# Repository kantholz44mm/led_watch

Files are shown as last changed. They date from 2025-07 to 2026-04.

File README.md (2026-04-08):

# Description

It's a wristwatch using LEDs to show the current time. This repository contains one major folder for the hardware part, which contains a KiCAD project with the schematics & PCB layout, as well as a FreeCAD project with 3D-printable parts for the case. You can find instructions on how to use each "part" of the repo in the subfolders.

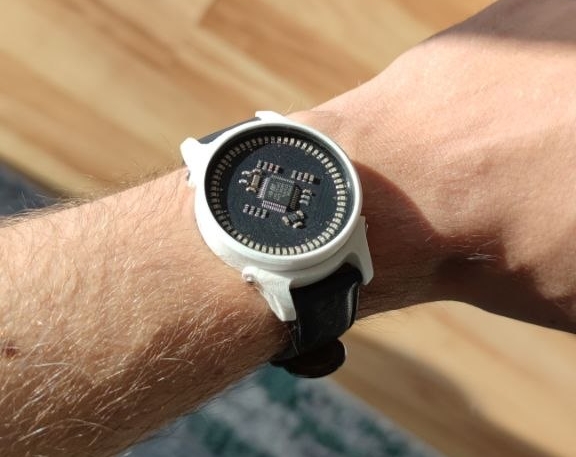
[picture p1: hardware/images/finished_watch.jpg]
Image of finished Wristwatch


# How it works

The watch has a (very) low power STM32 microcontroller, as well as a Bosch BMA400 accelerometer for user inputs. It also has a 32 kHz crystal for precise timekeeping. A ring of 60 LEDs shows the hour and minute hands when the watch is doubletapped on its X axis. When not displaying the time, all components are put into their lowest possible power modes, consuming ~9uA total. Since the device is powered by a single CR2032 or CR2016 coin cell on the back of the PCB, this results in a theoretical maximum runtime of up to ~2.9. I have not had time to test this fully, but my personal watch has been going strong on a single cell for around 7 months with daily use. Battery lifetime of course heavily depends on how often the display is activated.

# Design Goals

- Long battery life & Easy battery replacement
- Small diameter (currently 38mm without the case)
- Manufacturability (case is 3D-printable or machineable)
- Water-tightness

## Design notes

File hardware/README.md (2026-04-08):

# Schematics

The whole watch is built around an STM32L071 low power MCU. There's also a Bosch BMA400 accelerometer used for detecting taps and the absolute orientation for setting the time, bubble-level syle. The MCU has a 32KHz for precise timekeeping. The LED ring is segmented into 4 groups of 15 to drastically reduce routing complexity and part count. As a consequence, only 1 LED per group can be active at a time. In the current software, only 1 LED in total is ever on at a time. The accelerometer communicates with the MCU via I2C for configuration and has a shared interrupt line for wakeup. You can find the full schematics under `hardware/export/watch.pdf`.

# Case

There's two case designs, which are very similar: There's a Unibody with only one outer shell, as well as a bottom lid for easy battery replacement, and one body with two separate handle pieces, which makes the body part rotationally symmetric for those who might want to machine the parts on a lathe. For both cases, you'll need 4 1.6x8mm screws to hold everything together, as well as a 38mm watch-glass/crystal. You'll also need two gaskets, both of which can either be purchased, or, as I did, 3D printed from TPU. There's the FreeCAD project file, as well as STEP files for all parts. The STEP files can be found under `hardware/export/`.

# PCB

The PCB was created using KiCAD. The project includes part numbers for ordering with automated assembly from JLCPCB. You can find the exported gerber files (ready to order) in the folder `hardware/export`.

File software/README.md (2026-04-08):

# Description

The firmware of the watch currently implements showing the time and temperature, as well as setting the time. Every LED display feature has some neat animations where the lit up LED "runs" to the new target over some period of time.

Everything is built ontop of a custom HAL layer which uses only CMSIS headers as a dependency. As such, the firmware is fully self-contained as it is within the repo, with no other external dependencies.

# Prerequisites

- ARM compiler toolchain (`arm-none-eabi-xxx`)
- GNU Make
- Debugger/Programmer
- Needle adapter or soldering iron & wires

You will need an ARM compiler to build the firmware. The build process is done using a single Makefile. To flash the code to the device, you'll also need a programmer or debugger. I personally use a JLink one within VS Code, so there's a configuration for that in the project. The hardware currently only has testpoints for attaching a debugger via SWD, but they're quite big and can easily be soldered to.

# Getting started

To compile, just go into the `software` folder and do

`make`

This should output a finished binary at `software/bin/main.elf`.

# Using the firmware

The firmware implements the following state machine for its UX:

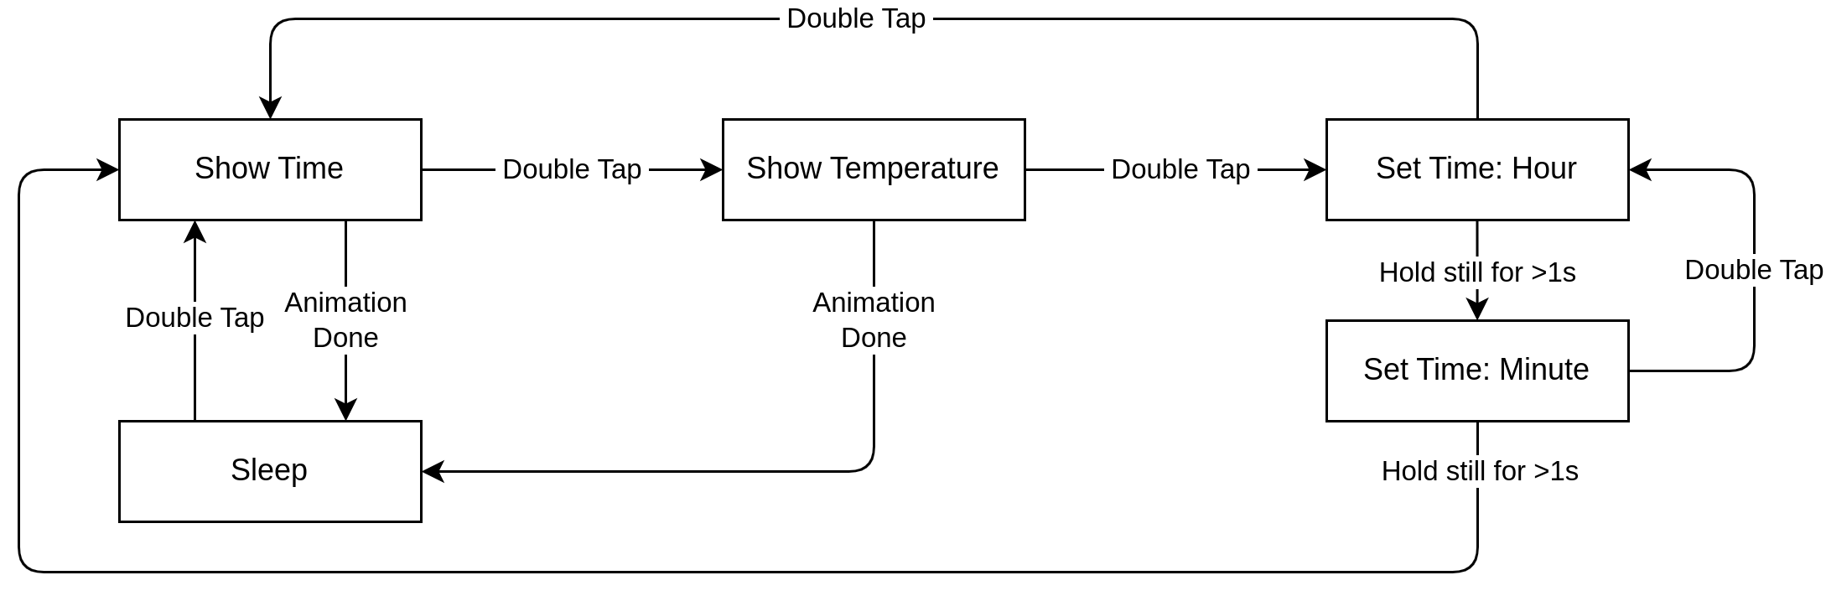
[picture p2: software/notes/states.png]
Image of the state machine of inputs


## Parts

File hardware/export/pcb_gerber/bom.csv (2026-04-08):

Designator | Footprint | Quantity | Value | LCSC Part #
C1, C10, C11, C2, C3, C4, C5, C9 | 0603 | 8 | 100nF | C91183
C12, C13 | 0603 | 2 | 22uF | C86295
C7, C8 | 0603 | 2 | 19pF | C527046
D1, D10, D11, D12, D13, D14, D15, D16, D17, D18, D19, D2, D20, D21, D22, D23, D24, D25, D26, D27, D28, D29, D3, D30, D31, D32, D33, D34, D35, D36, D37, D38, D39, D4, D40, D41, D42, D43, D44, D45, D46, D47, D48, D49, D5, D50, D51, D52, D53, D54, D55, D56, D57, D58, D59, D6, D60, D7, D8, D9 | 0603 | 60 | LED | C284922
R1, R2 | 0603 | 2 | 4.7k | C23162
R10, R8, R9 | 0603 | 3 | 22 | C23345
R3 | 0603 | 1 | 100K | C25805
R4, R5, R6, R7 | 0603 | 4 | 160 | C22814
U1 | LQFP-48_7x7mm_P0.5mm | 1 | STM32L071CBTx | C79758
U2 | LGA-12_2x2mm_P0.5mm | 1 | BOSCH BMA400 | C437655
Y1 | Crystal_SMD_3215-2Pin_3.2x1.5mm | 1 | 3131M-32.768DTTLRRL | C42438016

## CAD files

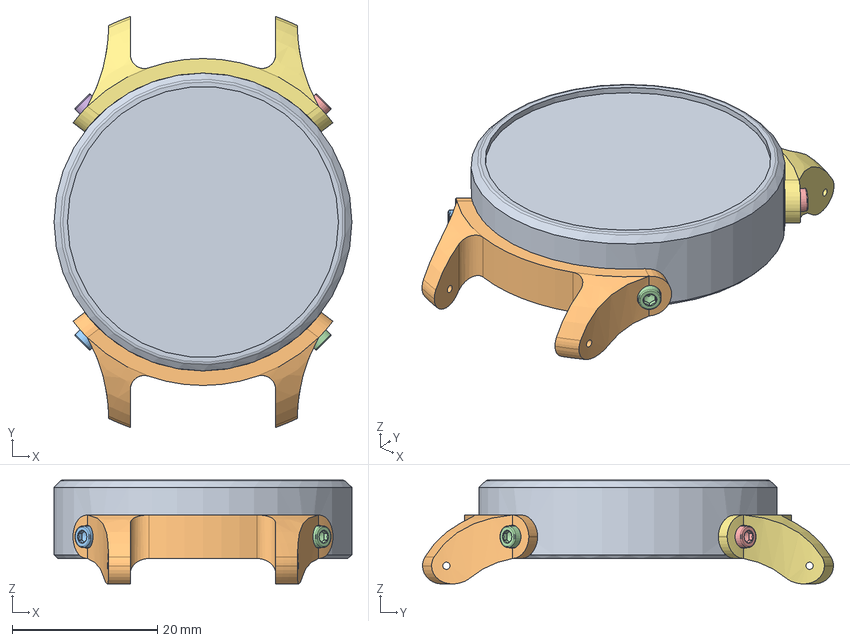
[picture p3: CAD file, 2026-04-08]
hardware/case.FCStd
41.0 x 56.6 x 14.3 mm
Glass
C_0603_1608Metric
LED_0603_1608Metric
LED_0603_1608Metric001
LED_0603_1608Metric002
R_0603_1608Metric
LED_0603_1608Metric003
R_0603_1608Metric001
LED_0603_1608Metric004
LED_0603_1608Metric005
LED_0603_1608Metric006
LED_0603_1608Metric007
LED_0603_1608Metric008
R_0603_1608Metric002
LED_0603_1608Metric009
LED_0603_1608Metric010
C_0603_1608Metric001
LED_0603_1608Metric011
LED_0603_1608Metric012
LED_0603_1608Metric013
C_0603_1608Metric002
LED_0603_1608Metric014
LED_0603_1608Metric015
LED_0603_1608Metric016
LED_0603_1608Metric017
R_0603_1608Metric003
LQFP-48_7x7mm_P0.5mm
R_0603_1608Metric004
R_0603_1608Metric005
LED_0603_1608Metric018
Crystal_SMD_3215-2Pin_3.2x1.5mm
C_0603_1608Metric003
R_0603_1608Metric006
C_0603_1608Metric004
LED_0603_1608Metric019
LED_0603_1608Metric020
LED_0603_1608Metric021
LED_0603_1608Metric022
LED_0603_1608Metric023
LED_0603_1608Metric024
LED_0603_1608Metric025
LED_0603_1608Metric026
LED_0603_1608Metric027
R_0603_1608Metric007
LED_0603_1608Metric028
LED_0603_1608Metric029
LED_0603_1608Metric030
LED_0603_1608Metric031
R_0603_1608Metric008
LED_0603_1608Metric032
LED_0603_1608Metric033
LED_0603_1608Metric034
LED_0603_1608Metric035
LED_0603_1608Metric036
C_0603_1608Metric005
LED_0603_1608Metric037
LED_0603_1608Metric038
LED_0603_1608Metric039
C_0603_1608Metric006
LED_0603_1608Metric040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

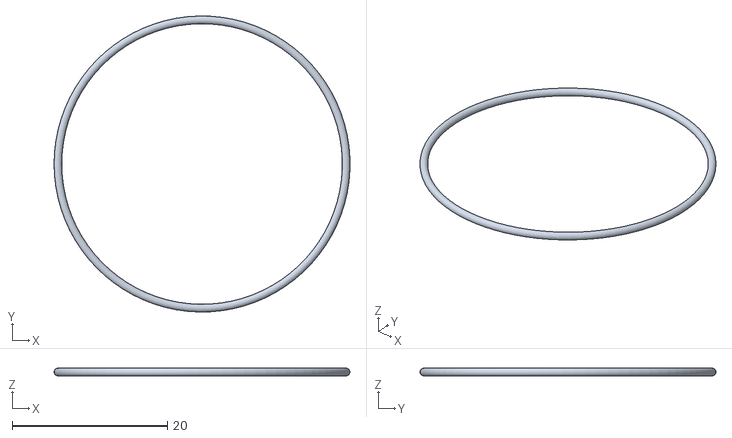
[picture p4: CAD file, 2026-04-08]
hardware/export/LowerGasket.stl
38.1 x 38.1 x 0.993

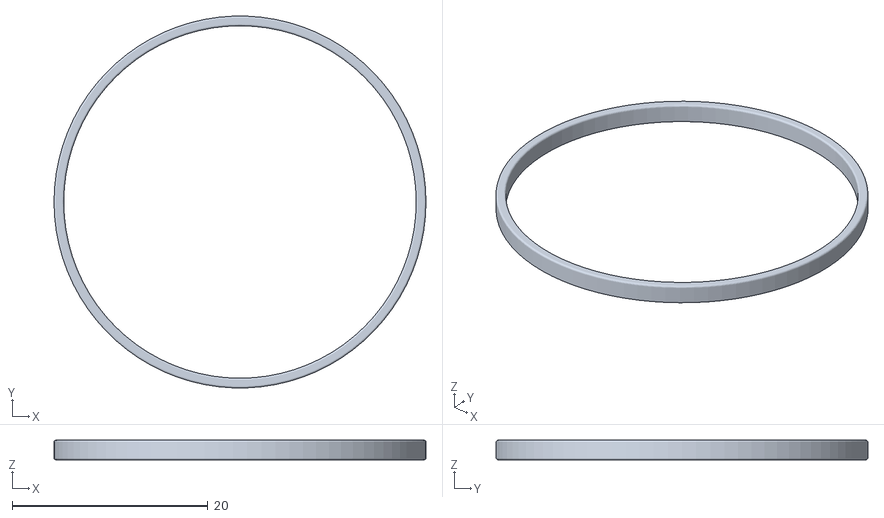
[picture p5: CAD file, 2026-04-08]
hardware/export/UpperGasket.stl
38.0 x 38.0 x 2.00

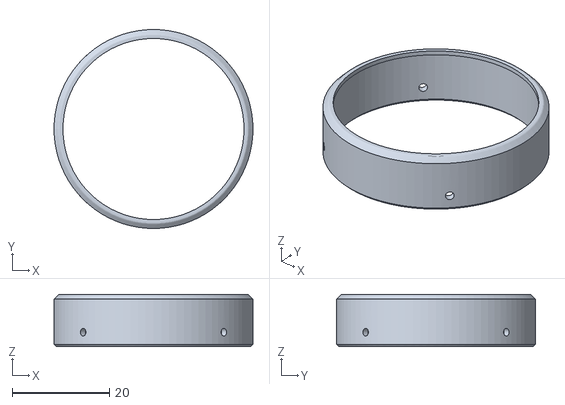
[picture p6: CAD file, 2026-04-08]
hardware/export/Body.stl
41.0 x 41.0 x 10.8

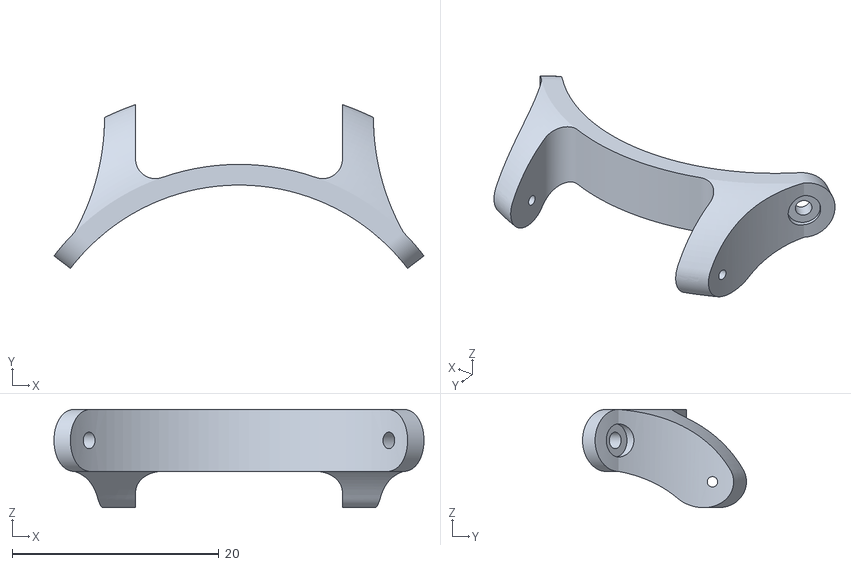
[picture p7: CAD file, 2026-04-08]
hardware/export/Handle.stl
35.8 x 15.8 x 9.50

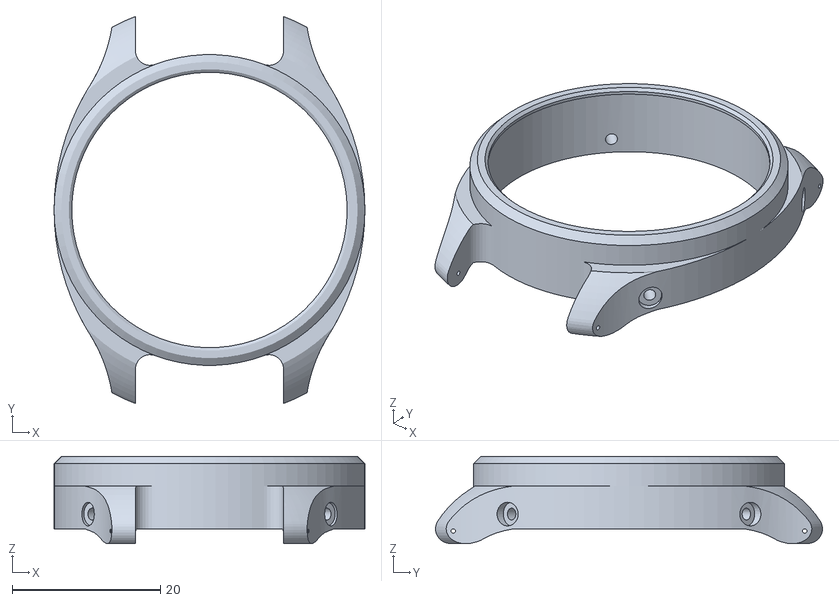
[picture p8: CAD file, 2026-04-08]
hardware/export/Unibody.stl
42.0 x 52.3 x 11.8

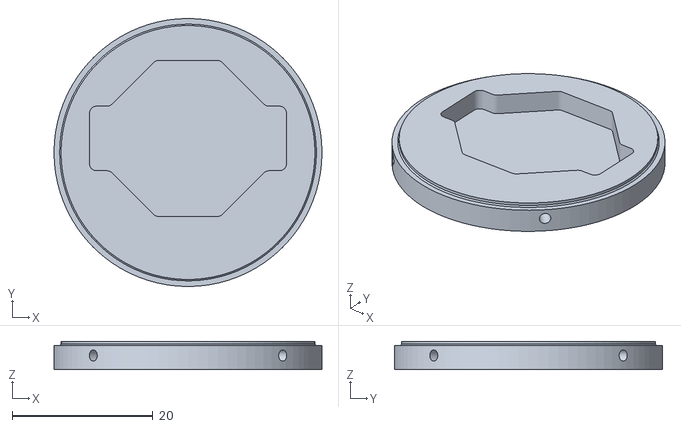
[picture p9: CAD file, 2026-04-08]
hardware/export/Bottom.stl
38.1 x 38.1 x 4.00

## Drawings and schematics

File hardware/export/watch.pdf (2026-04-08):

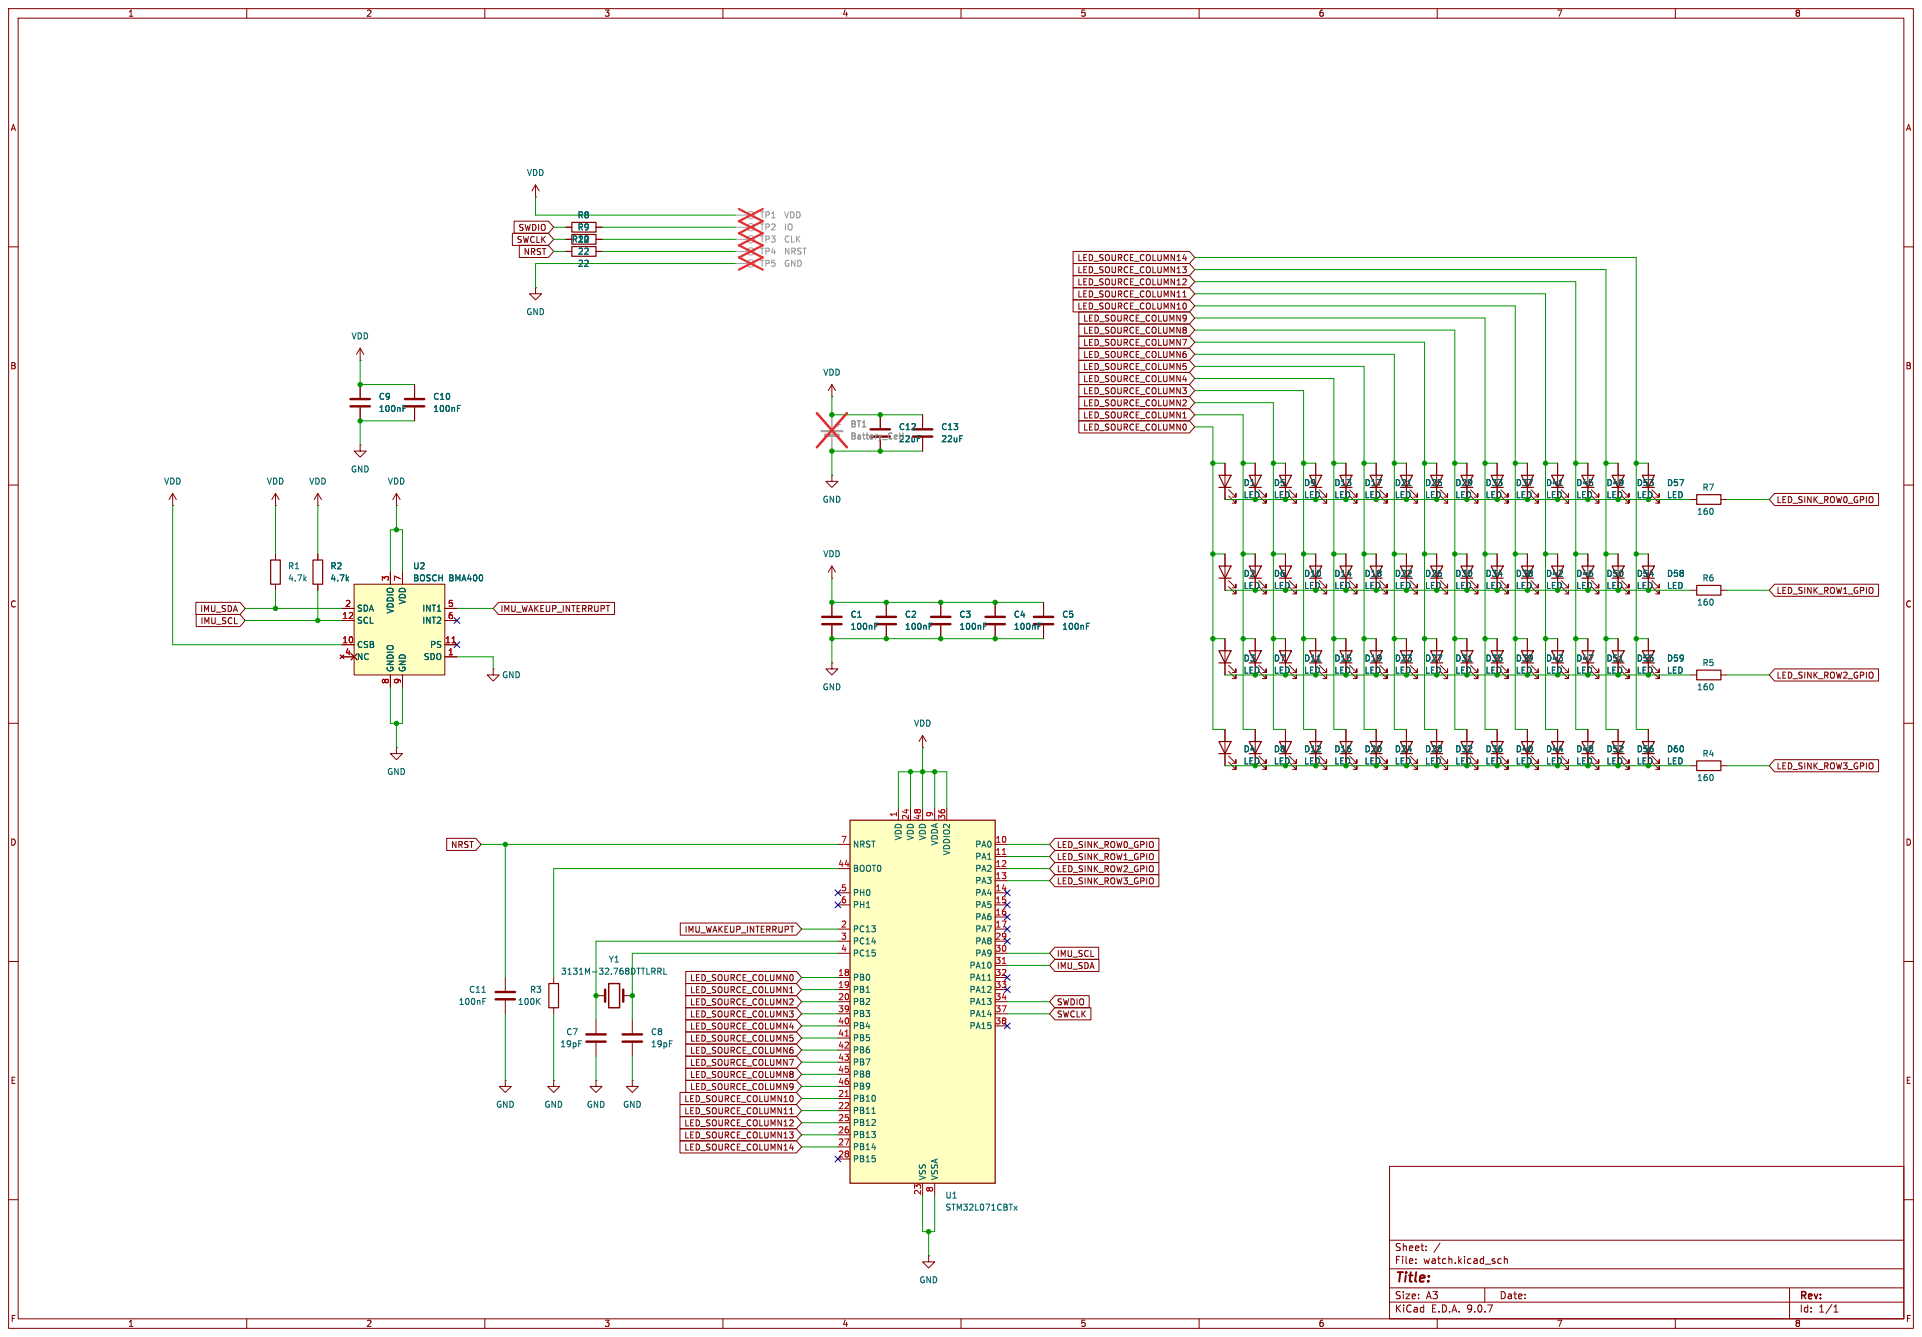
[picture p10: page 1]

1 VDD 24 VDD 48 VSS 23 VDDA

Id: 1/1 Title: File: watch.kicad_sch Sheet: / R3

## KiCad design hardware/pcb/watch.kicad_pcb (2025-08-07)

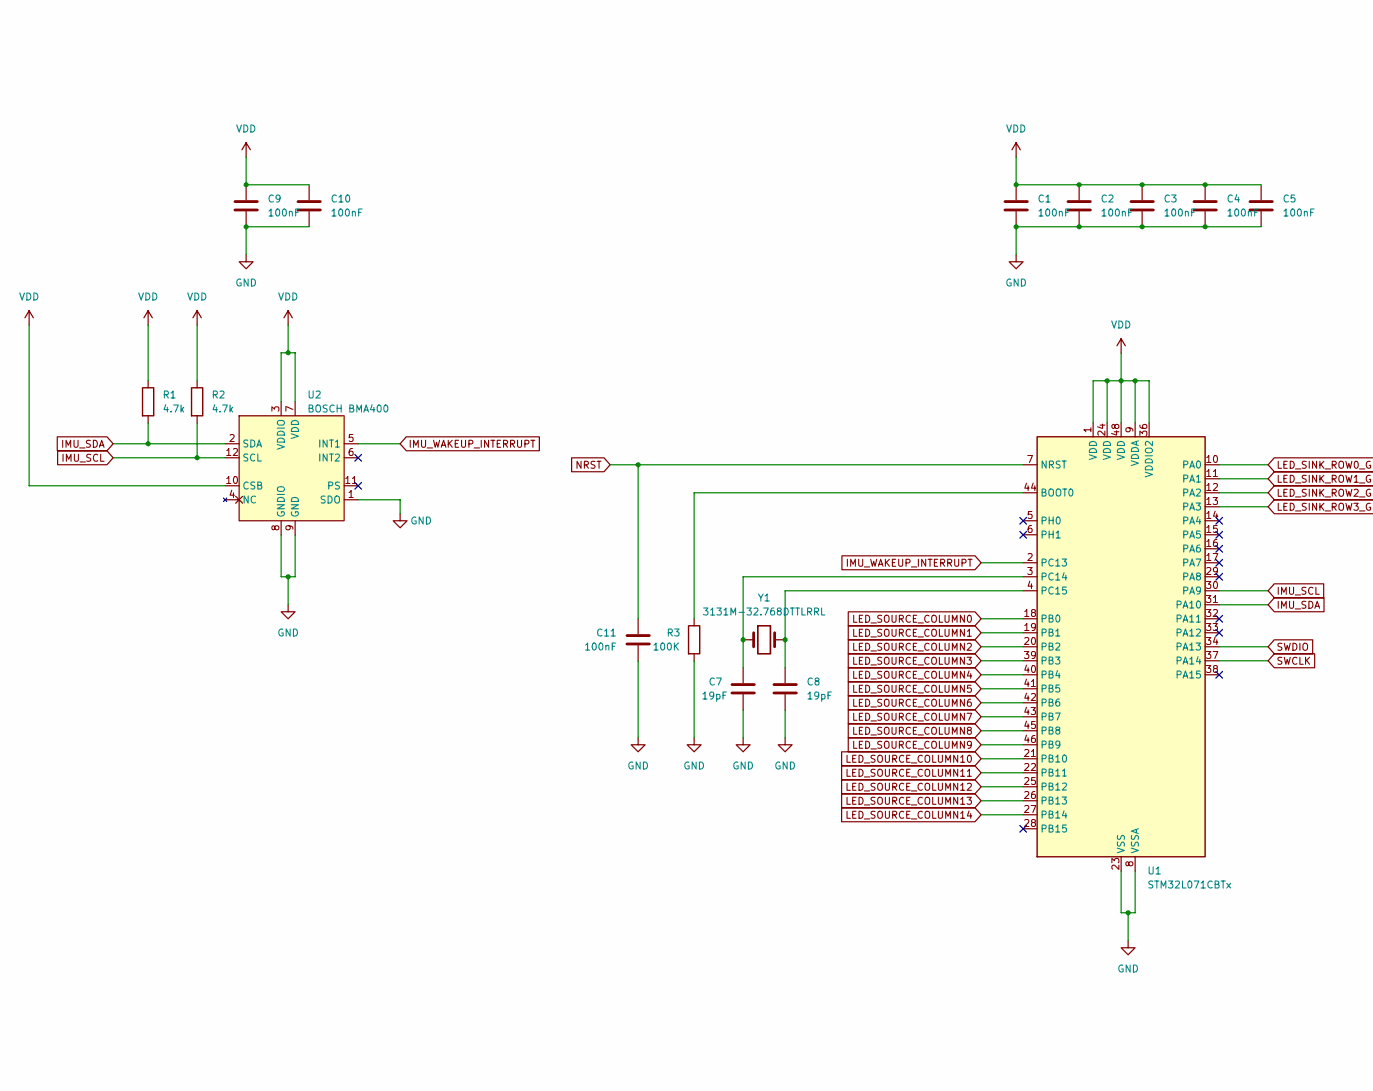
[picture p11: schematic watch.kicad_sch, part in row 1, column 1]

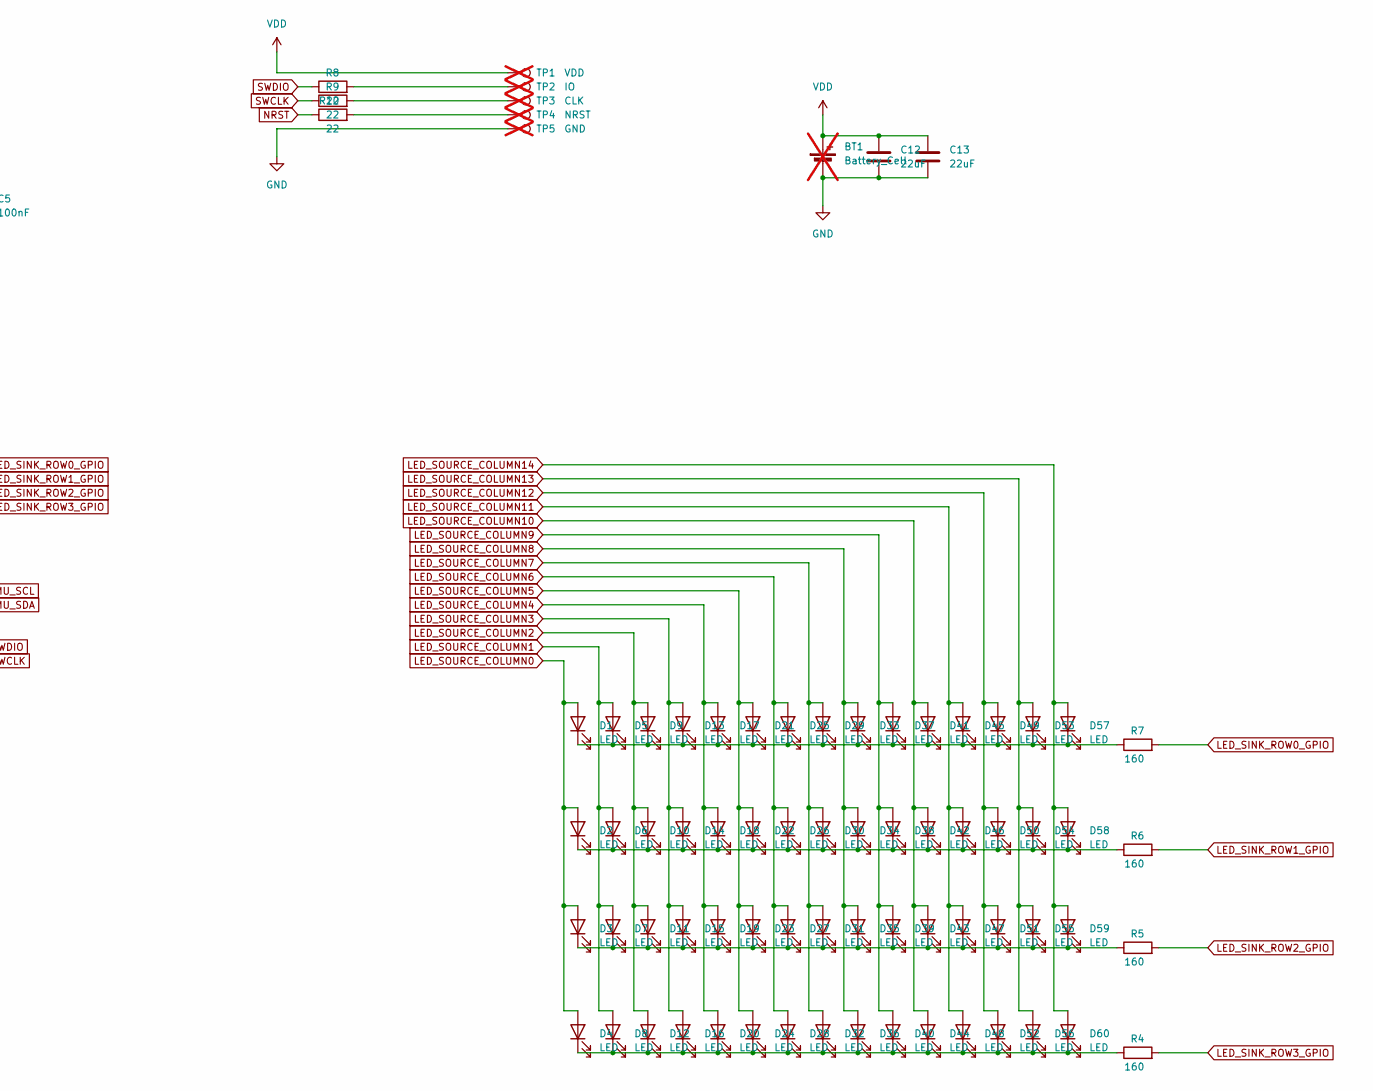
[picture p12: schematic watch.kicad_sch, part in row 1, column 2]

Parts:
BT1: Battery_Cell; BatteryHolder_MPD_BC2003_1x2032; not fitted
C1, C2, C3, C4, C5, C9, C10, C11: 100nF; C_0603_1608Metric; LCSC Part # C91183
C7, C8: 19pF; C_0603_1608Metric; LCSC Part # C527046
C12, C13: 22uF; C_0603_1608Metric; LCSC Part # C86295
D1, D2, D3, D4, D5, D6, D7, D8, D9, D10, D11, D12, D13, D14, D15, D16, D17, D18, D19, D20, D21, D22, D23, D24, D25, D26, D27, D28, D29, D30, D31, D32, D33, D34, D35, D36, D37, D38, D39, D40, D41, D42, D43, D44, D45, D46, D47, D48, D49, D50, D51, D52, D53, D54, D55, D56, D57, D58, D59, D60: LED; 0603; LCSC Part # C284922
R1, R2: 4.7k; R_0603_1608Metric; LCSC Part # C23162
R3: 100K; R_0603_1608Metric; LCSC Part # C25805
R4, R5, R6, R7: 160; R_0603_1608Metric; LCSC Part # C22814
R8, R9, R10: 22; R_0603_1608Metric; LCSC Part # C23345
TP1: VDD; TestPoint_Pad_D2.0mm; not fitted
TP2: IO; TestPoint_Pad_D2.0mm; not fitted
TP3: CLK; TestPoint_Pad_D2.0mm; not fitted
TP4: NRST; TestPoint_Pad_D2.0mm; not fitted
TP5: GND; TestPoint_Pad_D2.0mm; not fitted
U1: STM32L071CBTx; LQFP-48_7x7mm_P0.5mm; LCSC Part # C79758
U2: BOSCH BMA400; LGA-12_2x2mm_P0.5mm; LCSC Part # C437655
Y1: 3131M-32.768DTTLRRL; Crystal_SMD_3215-2Pin_3.2x1.5mm; LCSC Part # C42438016

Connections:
GND: BT1.2 (-), C1.1, C2.1, C3.1, C4.1, C5.1, C7.2, C8.2, C9.1, C10.1, C11.1, C12.1, C13.1, R3.2, TP5.1, U1.8 (VSSA), U1.23 (VSS), U1.35 (VSS), U1.47 (VSS), U2.1 (SDO), U2.8 (GNDIO), U2.9 (GND)
IMU_SCL: R2.2, U1.30 (PA9), U2.12 (SCL)
IMU_SDA: R1.2, U1.31 (PA10), U2.2 (SDA)
IMU_WAKEUP_INTERRUPT: U1.2 (PC13), U2.5 (INT1)
LED_SINK_ROW0_GPIO: R7.2, U1.10 (PA0)
LED_SINK_ROW1_GPIO: R6.2, U1.11 (PA1)
LED_SINK_ROW2_GPIO: R5.2, U1.12 (PA2)
LED_SINK_ROW3_GPIO: R4.2, U1.13 (PA3)
LED_SOURCE_COLUMN0: D1.2 (A), D2.2 (A), D3.2 (A), D4.2 (A), U1.18 (PB0)
LED_SOURCE_COLUMN1: D5.2 (A), D6.2 (A), D7.2 (A), D8.2 (A), U1.19 (PB1)
LED_SOURCE_COLUMN2: D9.2 (A), D10.2 (A), D11.2 (A), D12.2 (A), U1.20 (PB2)
LED_SOURCE_COLUMN3: D13.2 (A), D14.2 (A), D15.2 (A), D16.2 (A), U1.39 (PB3)
LED_SOURCE_COLUMN4: D17.2 (A), D18.2 (A), D19.2 (A), D20.2 (A), U1.40 (PB4)
LED_SOURCE_COLUMN5: D21.2 (A), D22.2 (A), D23.2 (A), D24.2 (A), U1.41 (PB5)
LED_SOURCE_COLUMN6: D25.2 (A), D26.2 (A), D27.2 (A), D28.2 (A), U1.42 (PB6)
LED_SOURCE_COLUMN7: D29.2 (A), D30.2 (A), D31.2 (A), D32.2 (A), U1.43 (PB7)
LED_SOURCE_COLUMN8: D33.2 (A), D34.2 (A), D35.2 (A), D36.2 (A), U1.45 (PB8)
LED_SOURCE_COLUMN9: D37.2 (A), D38.2 (A), D39.2 (A), D40.2 (A), U1.46 (PB9)
LED_SOURCE_COLUMN10: D41.2 (A), D42.2 (A), D43.2 (A), D44.2 (A), U1.21 (PB10)
LED_SOURCE_COLUMN11: D45.2 (A), D46.2 (A), D47.2 (A), D48.2 (A), U1.22 (PB11)
LED_SOURCE_COLUMN12: D49.2 (A), D50.2 (A), D51.2 (A), D52.2 (A), U1.25 (PB12)
LED_SOURCE_COLUMN13: D53.2 (A), D54.2 (A), D55.2 (A), D56.2 (A), U1.26 (PB13)
LED_SOURCE_COLUMN14: D57.2 (A), D58.2 (A), D59.2 (A), D60.2 (A), U1.27 (PB14)
NRST: C11.2, R10.1, U1.7 (NRST)
unnamed: D1.1 (K), D5.1 (K), D9.1 (K), D13.1 (K), D17.1 (K), D21.1 (K), D25.1 (K), D29.1 (K), D33.1 (K), D37.1 (K), D41.1 (K), D45.1 (K), D49.1 (K), D53.1 (K), D57.1 (K), R7.1
unnamed: D2.1 (K), D6.1 (K), D10.1 (K), D14.1 (K), D18.1 (K), D22.1 (K), D26.1 (K), D30.1 (K), D34.1 (K), D38.1 (K), D42.1 (K), D46.1 (K), D50.1 (K), D54.1 (K), D58.1 (K), R6.1
unnamed: D3.1 (K), D7.1 (K), D11.1 (K), D15.1 (K), D19.1 (K), D23.1 (K), D27.1 (K), D31.1 (K), D35.1 (K), D39.1 (K), D43.1 (K), D47.1 (K), D51.1 (K), D55.1 (K), D59.1 (K), R5.1
unnamed: D4.1 (K), D8.1 (K), D12.1 (K), D16.1 (K), D20.1 (K), D24.1 (K), D28.1 (K), D32.1 (K), D36.1 (K), D40.1 (K), D44.1 (K), D48.1 (K), D52.1 (K), D56.1 (K), D60.1 (K), R4.1
unnamed: R8.2, TP2.1
unnamed: R9.2, TP3.1
unnamed: R10.2, TP4.1
unnamed: R3.1, U1.44 (BOOT0)
unnamed: C7.1, U1.3 (PC14), Y1.1
unnamed: C8.1, U1.4 (PC15), Y1.2
SWCLK: R9.1, U1.37 (PA14)
SWDIO: R8.1, U1.34 (PA13)
VDD: BT1.1 (+), C1.2, C2.2, C3.2, C4.2, C5.2, C9.2, C10.2, C12.2, C13.2, R1.1, R2.1, TP1.1, U1.1 (VDD), U1.9 (VDDA), U1.24 (VDD), U1.36 (VDDIO2), U1.48 (VDD), U2.3 (VDDIO), U2.7 (VDD), U2.10 (CSB)

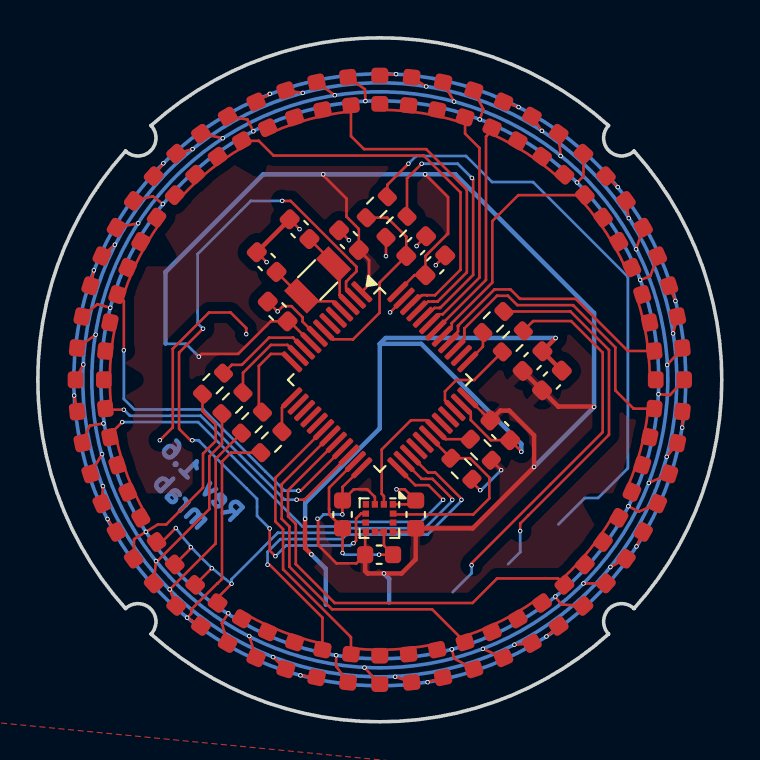
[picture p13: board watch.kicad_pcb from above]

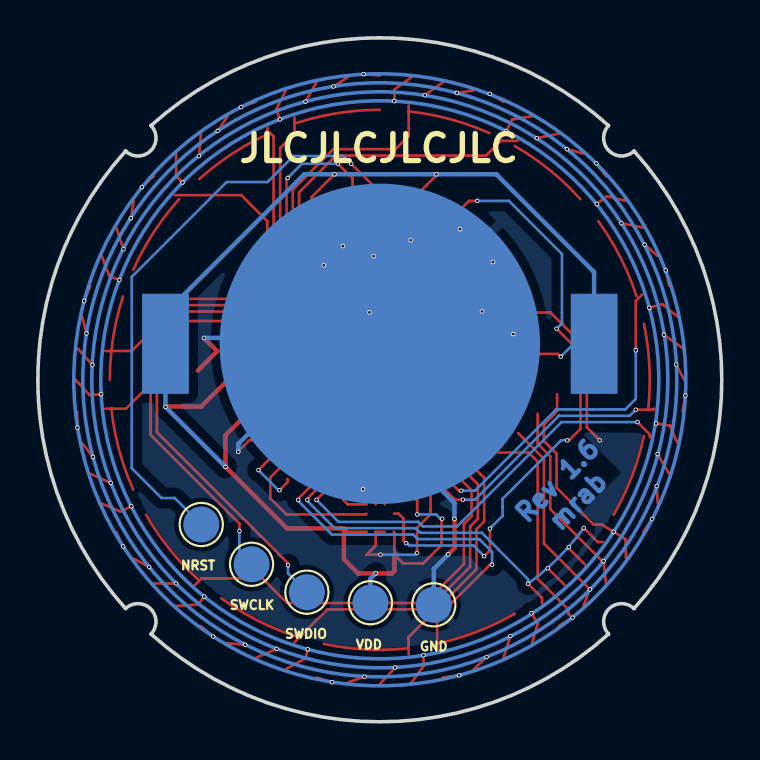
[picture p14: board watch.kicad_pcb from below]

Board: 2 copper layers, 38.0 x 38.0 mm, 91 parts (6 on the bottom side), 37 nets.

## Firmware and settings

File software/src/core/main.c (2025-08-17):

#include "hal/led.h"
#include "hal/i2c.h"
#include "hal/time.h"
#include "hal/gpio.h"
#include "hal/bma400.h"
#include "hal/rtc.h"
#include "animation.h"
#include "app/app.h"

int main(void)
{
    // initialize every peripheral needed
    time_init();
    rtc_init();
    led_init();
    i2c_init();
    bma400_init();
    animation_init();

    // the workhorse
    app_run();

    return 0;
}

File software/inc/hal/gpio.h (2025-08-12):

#pragma once
#include "types.h"
#include "cmsis/stm32l071xx.h"

#define GPIO_LOW   0
#define GPIO_HIGH  1

typedef enum {

    GPIO_PORT_A = 0,
    GPIO_PORT_B = 1,
    GPIO_PORT_C = 2,
    GPIO_PORT_D = 3,
    GPIO_PORT_E = 4,
    GPIO_PORT_H = 7

} gpio_port_t;

typedef enum {

    GPIO_MODE_INPUT     = 0b00,
    GPIO_MODE_OUTPUT    = 0b01,
    GPIO_MODE_ALTERNATE = 0b10,
    GPIO_MODE_ANALOG    = 0b11

} gpio_mode_t;


typedef enum {

    GPIO_OUTPUT_MODE_PUSHPULL  = 0b0,
    GPIO_OUTPUT_MODE_OPENDRAIN = 0b1

} gpio_output_mode_t;


typedef enum {

    GPIO_OUTPUT_SPEED_LOW       = 0b00,
    GPIO_OUTPUT_SPEED_MEDIUM    = 0b01,
    GPIO_OUTPUT_SPEED_HIGH      = 0b10,
    GPIO_OUTPUT_SPEED_VERY_HIGH = 0b11,

} gpio_output_speed_t;


typedef enum {

    GPIO_PULLUP_NONE = 0b00,
    GPIO_PULLUP_UP   = 0b01,
    GPIO_PULLUP_DOWN = 0b10,

} gpio_pulltype_t;



typedef struct {

    gpio_mode_t         mode;
    gpio_output_mode_t  output_mode;
    gpio_output_speed_t output_speed;
    gpio_pulltype_t     pulltype;
    u8                  alternate_mode;

} gpio_config_t;

void gpio_config(gpio_port_t port, u8 pin, gpio_config_t config);
u8 gpio_read(gpio_port_t port, u8 pin);
void gpio_write(gpio_port_t port, u8 pin, u8 value);

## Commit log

2021-11-21 Initial Draft
    [LED_Driver.sch, PowerSupply.sch, watch.kicad_pcb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]
2021-11-21 no more vias below metallic components; cleaned up some tracks
    [watch.kicad_pcb, watch.sch]
2021-11-22 V2 after Feedback
    [LED_Driver.sch, watch.kicad_pcb, watch.sch]
2021-11-24 testing gogs
    [LED_Driver.sch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]
2022-03-23 60 LED version
    [LED_Driver.kicad_sch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]
2022-04-07 as ordered
    [watch-B_Cu.gbl, watch-B_Cu.gbr, watch-B_Mask.gbr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]
2022-05-26 as ordered V1.4
    [LED_Driver.kicad_sch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]
2024-06-23 V2 initial schematic
    [LED_Driver.kicad_sch, LED_Driver.sch, LED_Matrix.kicad_sch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]
2024-06-24 V2 PCB first draft
    [LED_Matrix.kicad_sch, accel.kicad_sch, power.kicad_sch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]
2024-06-24 cleaned up silkscreen
    [watch.kicad_pcb]
2024-06-26 PCB V2
    [accel.kicad_sch, power.kicad_sch, watch.kicad_pcb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]
2024-07-24 small fixes
    [bom.csv, designators.csv, positions.csv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]
2024-07-30 good to go
    [watch.kicad_pcb]
2024-08-01 ready for ordering?
    [BOM-watch.csv, bom.csv, designators.csv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]
2025-05-21 clean slate.
    [BOM-watch.csv, LED_Driver.kicad_sch, LED_Driver.sch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]
2025-05-21 V3 first schematic draft done
    [watch.kicad_pcb, watch.kicad_sch]
2025-05-21 added unfinished footprint for DFN0606 FETs
    [watch.kicad_pcb, watch.kicad_sch]
2025-05-22 added DFN0606 footprint
    [watch.kicad_pcb, watch.kicad_sch]
2025-07-14 removed low side FETs, started PCB
    [outline.FCStd, outline.dxf, watch.kicad_pcb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]
2025-07-16 V1.6 basic layout done
    [watch.kicad_pcb, watch.kicad_sch]
2025-07-17 V1.6 done?
    [bom.csv, designators.csv, positions.csv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]
2025-07-17 moved stuff around, added .gitignore
    [bom.csv, designators.csv, outline.FCStd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]
2025-08-07 removed old project files
    [watch.kicad_pcb, watch.kicad_sch]
2025-08-07 moved hardware into its own folder
    [outline.FCStd, outline.dxf, watch.kicad_pcb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]
2025-10-28 various fixes for software, removed second hand
    [animation.c]
2025-10-31 case V2 started
    [case.FCStd, watch.step]
2025-11-17 added new case design
    [case.FCStd]
2026-04-07 fixed geometry of unibody (visual)
    [case-Body.stl, case-Bottom.stl, case.FCStd]
2026-04-08 moved around stuff and added sort of proper READMEs
    [case-Body.stl, case-Bottom.stl, outline.FCStd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]
2026-04-08 added Body & Unibody into single FreeCAD project, added export STLs for Cases
    [Body.stl, Bottom.stl, Handle.stl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]
2026-04-08 added export files for binary, Gerbers for PCB
    [bom.csv, designators.csv, positions.csv]
2026-04-08 added hardware README
    [watch.kicad_sch]
